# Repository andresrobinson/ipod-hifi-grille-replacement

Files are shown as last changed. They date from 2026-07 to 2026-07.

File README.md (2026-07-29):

# iPod Hi-Fi Grille Replacement

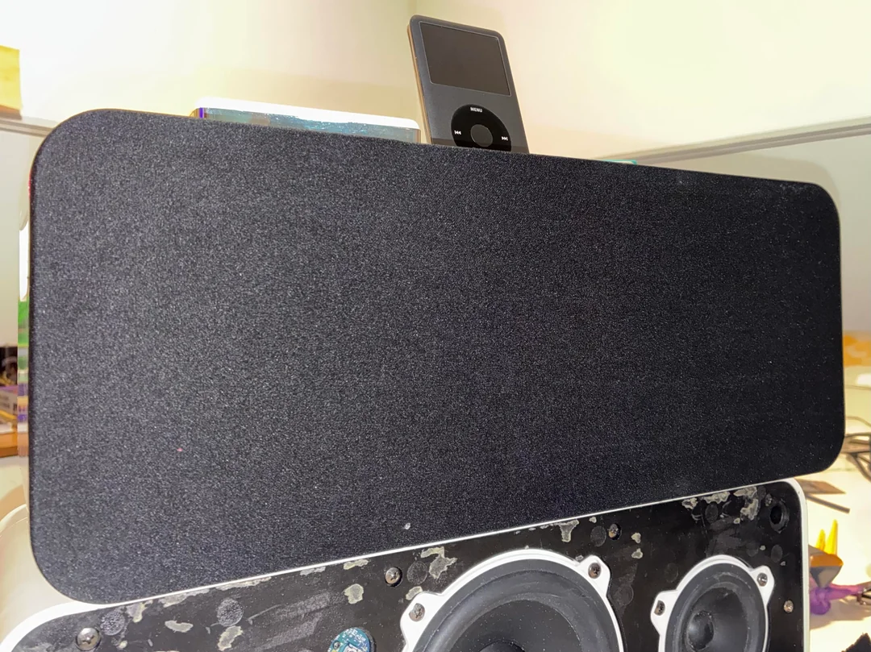
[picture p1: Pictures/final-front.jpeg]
Finished prototype


A 3D-printable replacement front grille frame for the **Apple iPod Hi-Fi A1121**, designed to be covered with fabric and mounted using replaceable screw-in pegs.

This project is meant for iPod Hi-Fi units with a missing or damaged original front grille. The replacement uses a printed support frame hidden behind fabric, so the visible front remains a clean fabric panel rather than a plastic printed mesh.

This is an independent repair/restoration project. It is not an original Apple part and is not affiliated with or endorsed by Apple.

---

## Quick Links

- [What this is](#what-this-is)
- [Files included](#files-included)
- [Parts overview](#parts-overview)
- [Materials](#materials)
- [Assembly](#assembly)
- [Fabric Installation (v1 - Glued)](#fabric-installation-v1)
- [Fabric Installation (v2 - Press Fit)](#fabric-installation-v2)
- [Mounting pegs](#mounting-pegs)
- [Known notes](#known-notes)
- [Development log](DEVELOPMENT.md)
- [Credits](#credits)
- [License](#license)

---

## What This Is {#what-this-is}

This is a replacement front grille assembly for the Apple iPod Hi-Fi.

The design is made from:

- three main printed frame sections;
- replaceable screw-in mounting pegs;
- glued fabric retaining strips;
- an optional assembly support to help align the frame sections during gluing;
- fabric stretched over the printed frame.

The printed frame is designed to sit behind the fabric. The fabric is the visible surface.

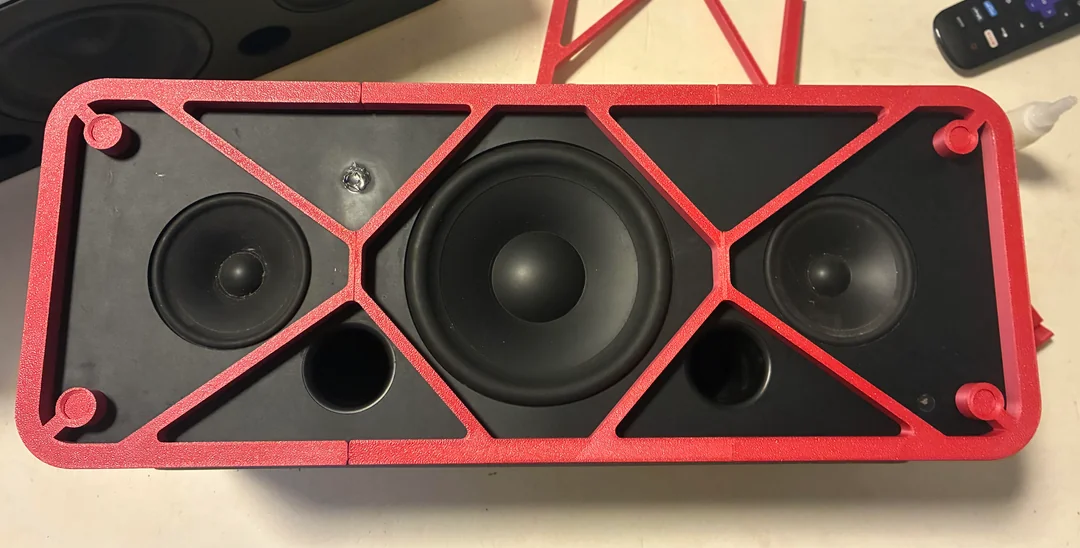
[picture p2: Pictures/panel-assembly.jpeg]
Panel assembly


---

## Files Included {#files-included}

The repository includes:

- a Fusion 360 source file;
- OBJ exports for the printable parts;
- documentation photos in the `Pictures/` folder;
- this README;
- a separate development log in [`DEVELOPMENT.md`](DEVELOPMENT.md).

The OBJ files are intended to include the main grille frame sections, replaceable pegs, retaining strips, and optional assembly support.

---

## Parts Overview {#parts-overview}

### Main Frame

The grille frame is split into three main parts so it can fit on a small 3D printer, including the Bambu Lab A1 Mini.

### Assembly Support

An optional assembly support is included to help align the frame sections during gluing. It is not part of the final visible grille.

Use of the assembly support is optional, but recommended.

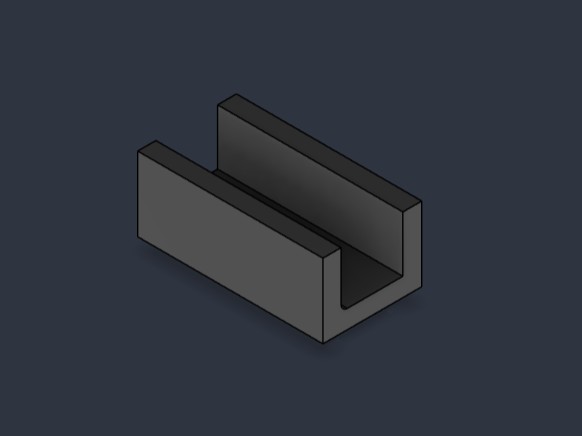
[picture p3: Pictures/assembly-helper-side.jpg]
Side assembly helper


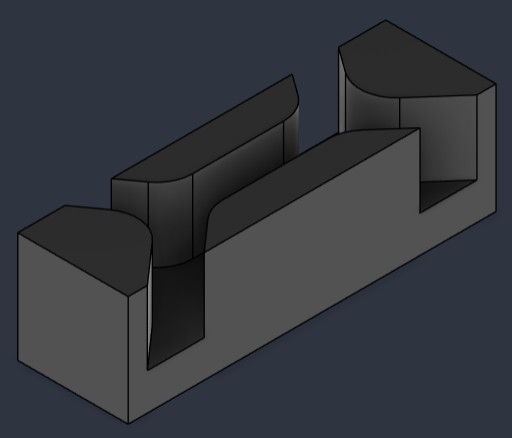
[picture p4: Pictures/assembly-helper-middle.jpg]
Middle assembly helper


### Retaining Strips

The retaining strips are used to hold the fabric in the fabric retention channel. There are two versions:
v1: Requires retainign strips to be glued in place after the fabric is stretched over the frame.

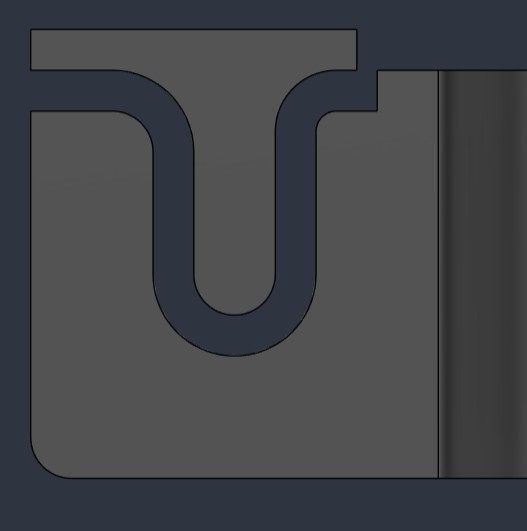
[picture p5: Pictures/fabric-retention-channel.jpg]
Fabric retention channel v1


v2: Allows retaining strip to be press fitted into the channel.

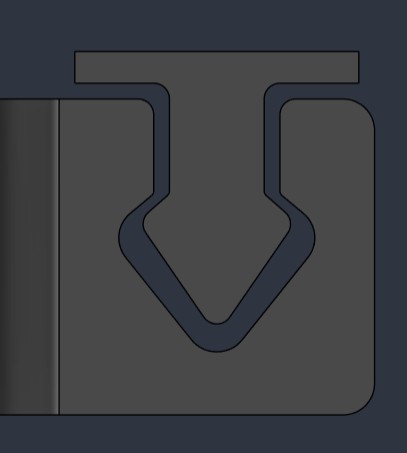
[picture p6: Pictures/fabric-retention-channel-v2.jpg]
Fabric retention channel v2


### Replaceable Pegs

The mounting pegs are separate screw-in parts. This allows the peg design to be changed later without reprinting the full frame.

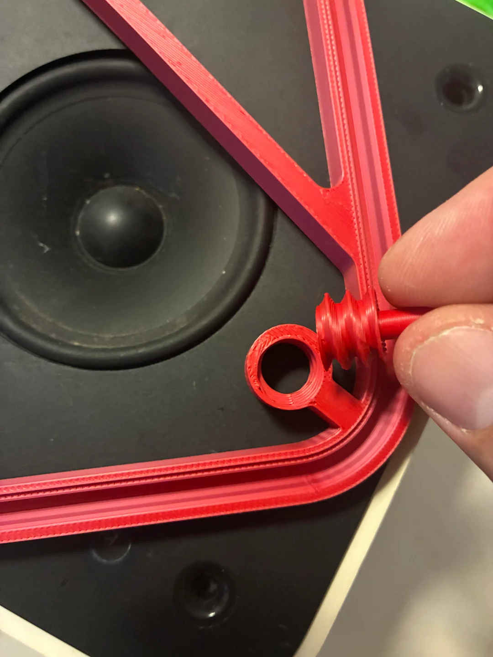
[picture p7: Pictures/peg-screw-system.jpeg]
Peg screw system


---

## Materials {#materials}

Recommended:

- printed frame parts;
- acoustically transparent speaker cloth, or thin fabric for testing;
- glue for joining the printed frame sections;
- glue for the fabric retaining strips;
- optional adhesive for locking the pegs after final test fitting.

For the first successful prototype, very thin neoprene was used as a proof-of-concept fabric. It gave good coverage and worked well mechanically, but it should still be treated as a test material rather than a confirmed acoustically transparent speaker cloth.

For a final audio-focused build, proper speaker grille cloth is recommended.

Avoid thick upholstery fabric, felt, dense neoprene, metal mesh, mosquito screen, or any fabric that noticeably muffles the speakers.

---

## Assembly {#assembly}

Suggested assembly order:

1. Print the three main frame sections.
2. Print the replaceable mounting pegs.
3. Print the fabric retaining strips.
4. Print the optional assembly support.
5. Test fit the main frame sections on the iPod Hi-Fi fascia.
6. Test fit the pegs in the mounting holes.
7. Adjust or swap peg type if needed.
8. Use the assembly support to align the main frame sections.
9. Glue the main frame sections together.
10. Let the frame glue fully cure.

---

## Fabric Installation (v1 - Glued) {#fabric-installation-v1}

The frame includes a fabric retention channel. The fabric is stretched over the frame, pressed into the channel, and held by glued retaining strips.

This is intended to make fabric installation cleaner than simply wrapping and gluing fabric around the back of the frame.

The retaining strips are not intended to be routinely removable. They are part of the final assembly.

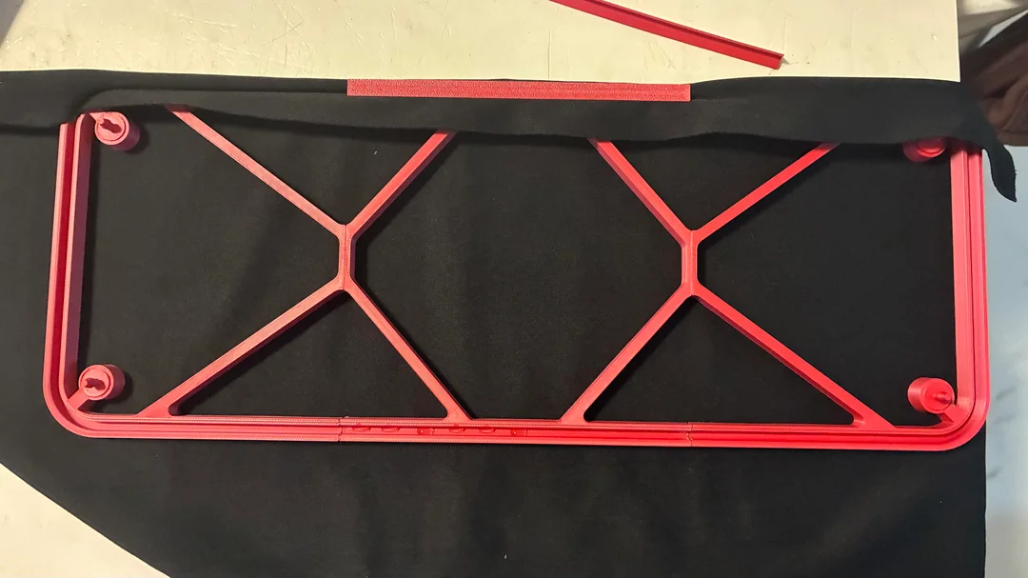
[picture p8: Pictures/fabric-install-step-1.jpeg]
Fabric installation step 1


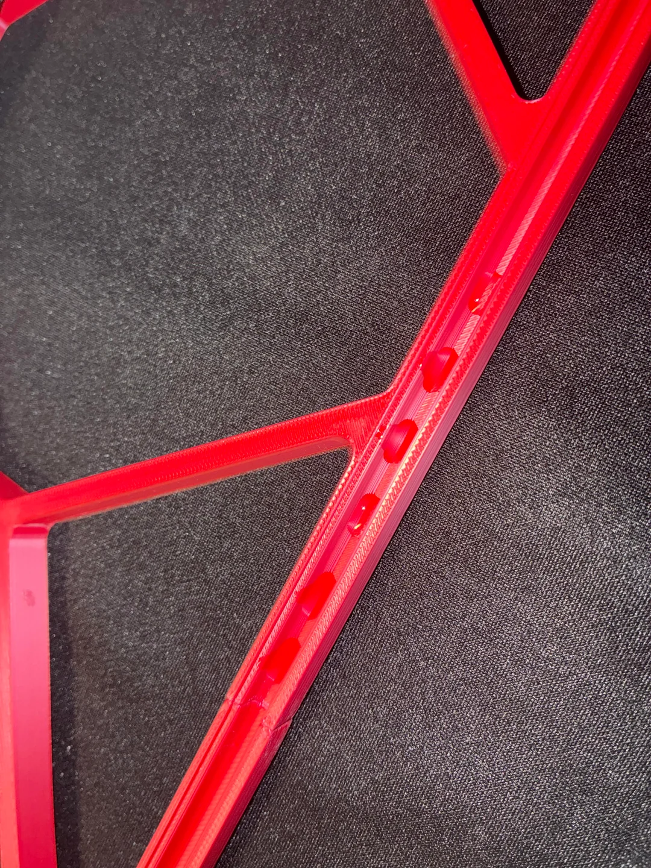
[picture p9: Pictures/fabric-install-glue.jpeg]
Fabric installation glue


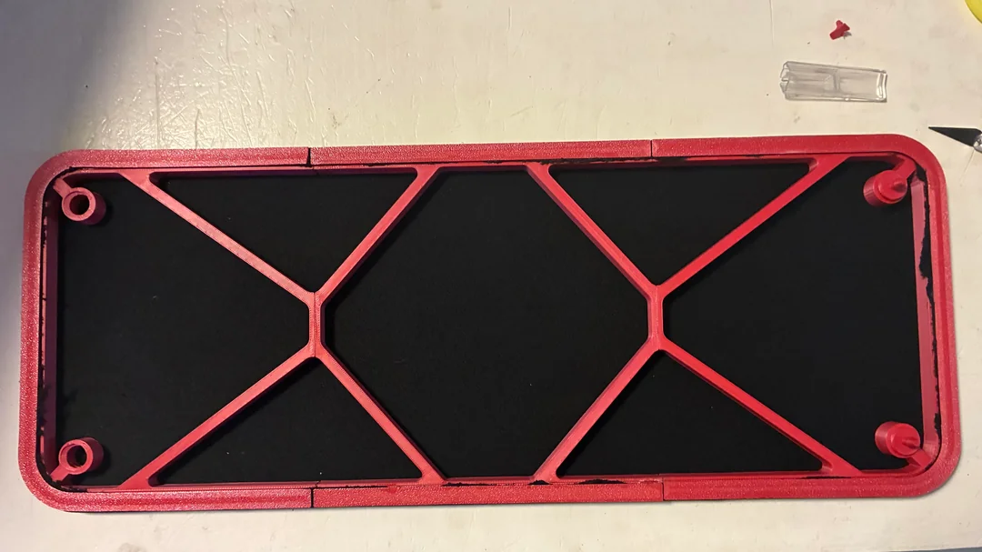
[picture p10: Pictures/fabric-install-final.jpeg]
Fabric installation final


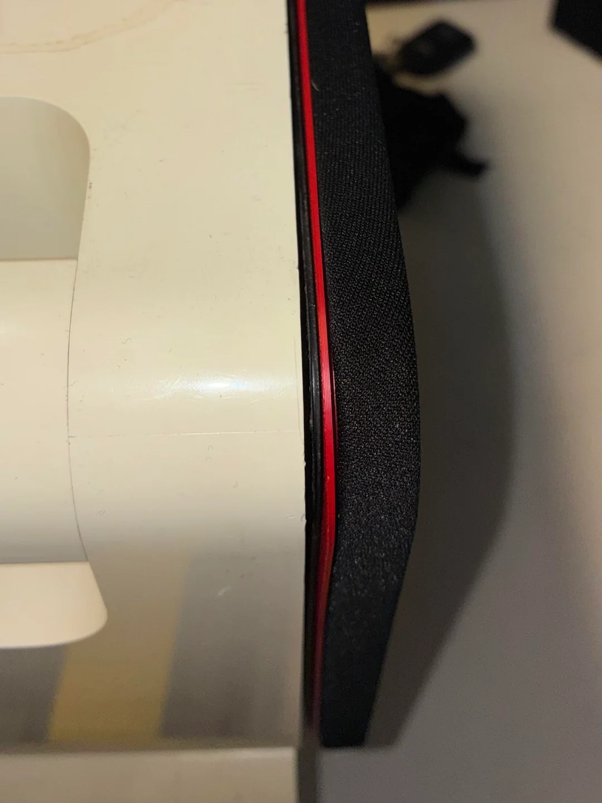
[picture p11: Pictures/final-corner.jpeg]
Final corner


## Fabric Installation (v2 - Press Fit) {#fabric-installation-v2}

The frame includes a fabric retention channel. The fabric is stretched over the frame, pressed into the channel, and held by press fit retaining strips.

This is intended to make fabric installation cleaner and more repeatable than simply wrapping and gluing fabric around the back of the frame or gluing into the channel.

The retaining strips are not intended to be routinely removable. They are part of the final assembly.

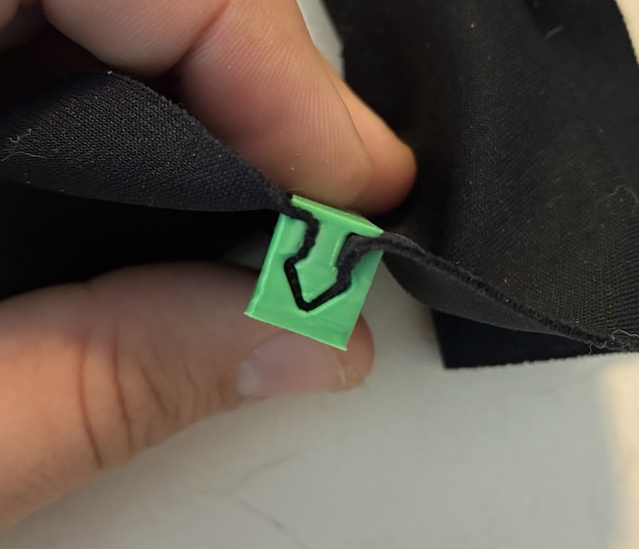
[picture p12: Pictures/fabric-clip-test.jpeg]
Fabric retention test


---

## Mounting Pegs {#mounting-pegs}

The mounting pegs are screw-in parts installed from the back of the grille frame.

Current thread specification:

```text
Thread diameter: 14 mm
Pitch: 3.5 mm
Profile: 60° trapezoidal
Tolerance class: 0.8 mm
```

The pegs can be installed before or after the fabric is mounted, since they do not interfere with the fabric or retaining strips.

If you do not plan to remove the pegs later, they can be glued in place after the final fit is confirmed.

### Mounting Hole Variation

A variation was found between two iPod Hi-Fi units.

On one unit, a 5 mm peg fit well. On another, the same peg would not go in. The fascia appears to have a small plastic retaining feature inside the mounting hole, probably intended to hold the original grille pegs in place.

Because of this, the design uses replaceable pegs.

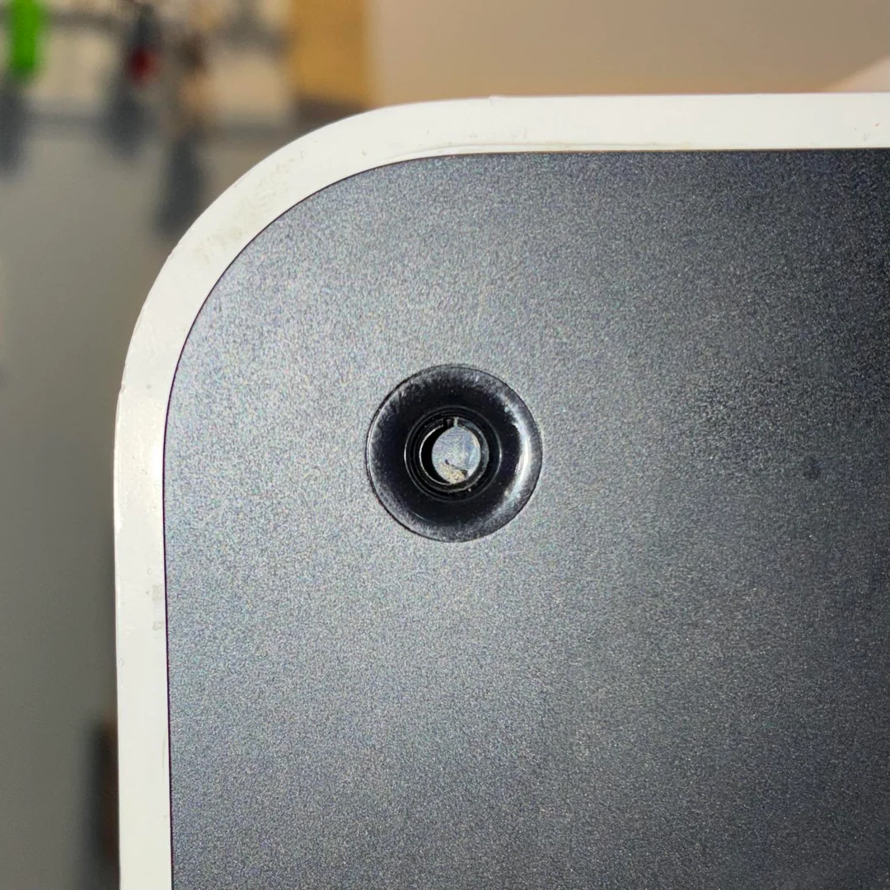
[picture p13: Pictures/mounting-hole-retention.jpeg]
Mounting hole with retention feature


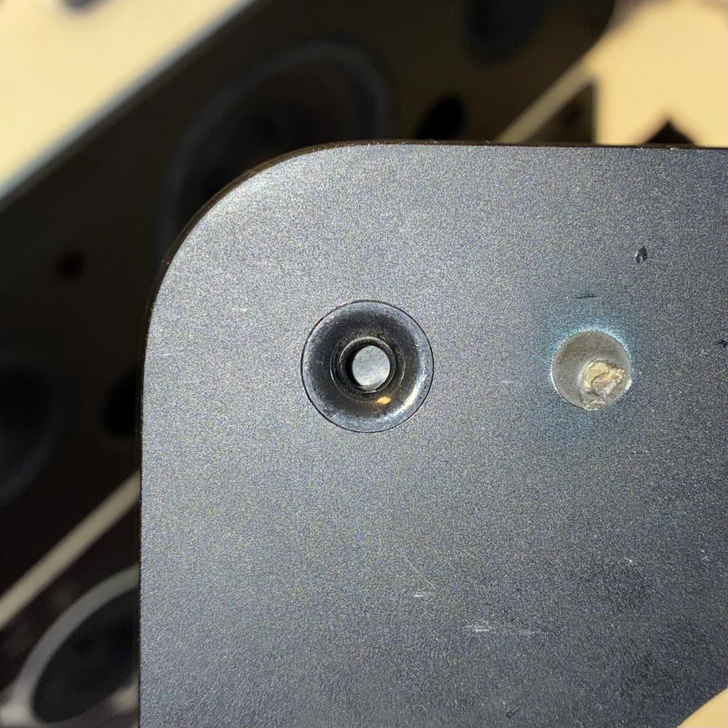
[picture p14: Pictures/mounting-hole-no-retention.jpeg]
Mounting hole without retention feature


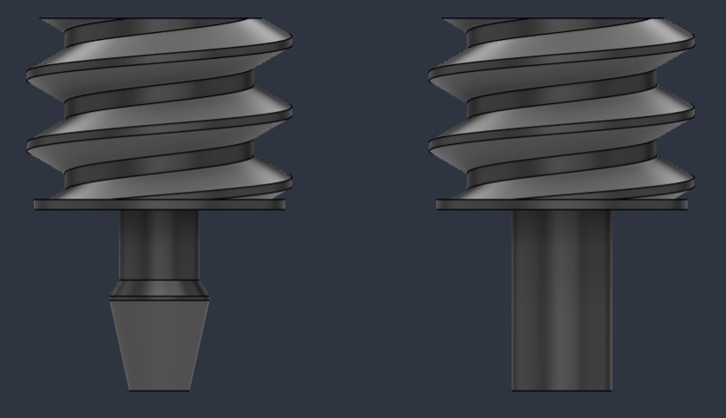
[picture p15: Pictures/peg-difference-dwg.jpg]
Peg type comparison


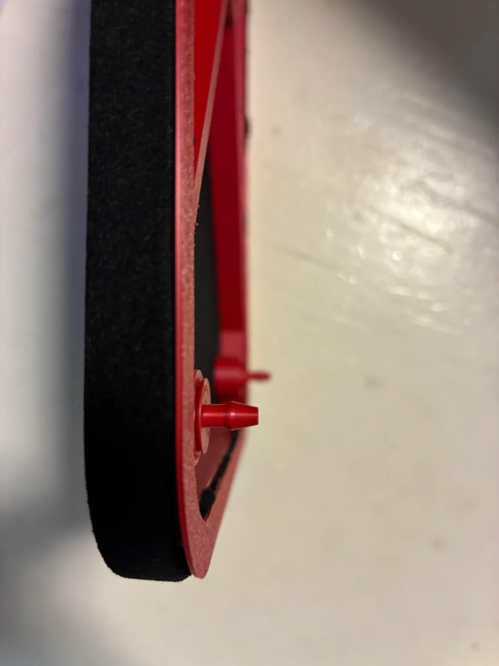
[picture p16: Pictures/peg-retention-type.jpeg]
Retention peg type


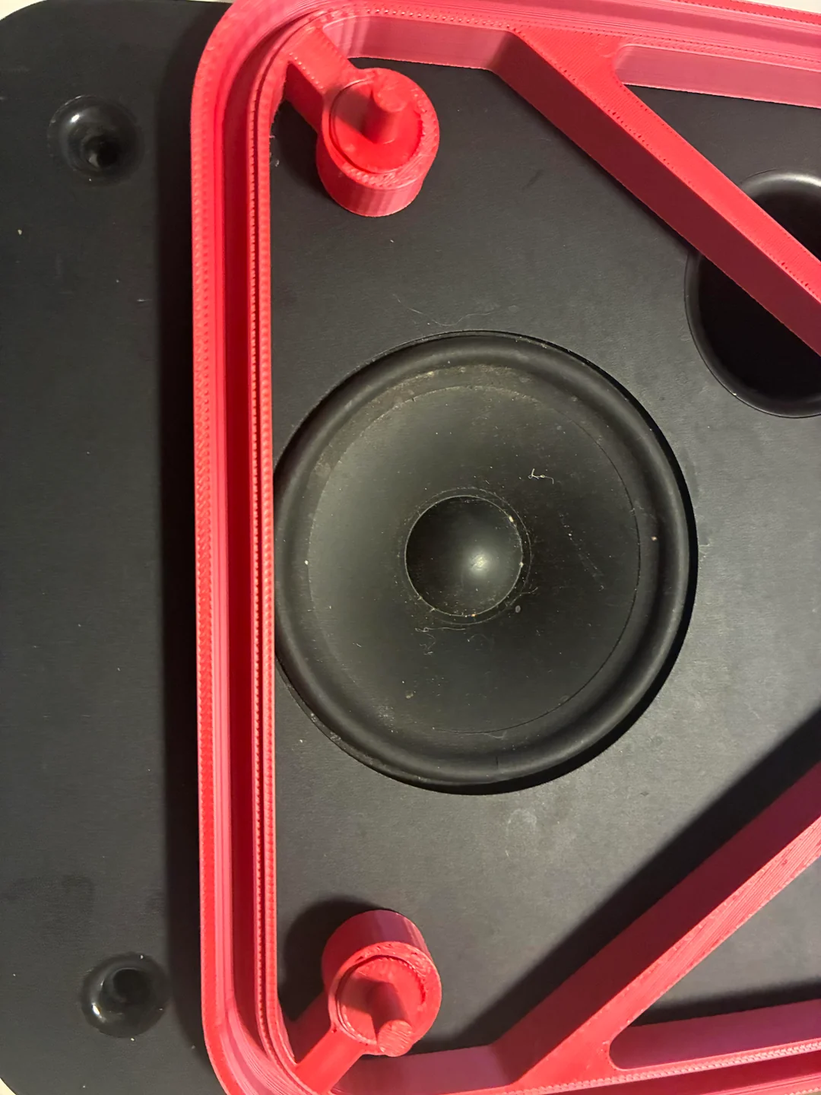
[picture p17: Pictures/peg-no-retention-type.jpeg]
No-retention peg type


---

## Known Notes {#known-notes}

- This is a replacement part, not an original Apple part.
- The fit was developed using real iPod Hi-Fi units, but small variation may exist between units.
- The mounting peg system is intentionally replaceable to make future improvements easier.
- The prototype fabric shown in some photos is very thin neoprene. It is useful for proving the assembly, but proper speaker grille cloth is still recommended for best acoustic transparency.
- Test fit everything before gluing.
- Do not force the pegs into the fascia. If the fit is too tight, change the peg design or adjust the print.

---

## Development Log {#development-log}

The design process, measurement approach, corner-radius tests, peg-spacing work, and thread decisions are documented separately in [`DEVELOPMENT.md`](DEVELOPMENT.md).

The README is kept focused on printing and assembly so people who only want to replicate the part do not need to read the full development history.

---

## Credits {#credits}

This project was helped by the following public resources:

- [`jake-b/iPod-HiFi-Tweeters`](https://github.com/jake-b/iPod-HiFi-Tweeters), which documents iPod Hi-Fi disassembly, fascia work, and speaker mesh frame construction.
- [`BalzGuenat/CustomThreads`](https://github.com/BalzGuenat/CustomThreads), which provides Fusion 360 thread profiles designed for 3D-printed threads.
-  Reddit user `u/sparkyblaster`, for the helpful comment about the original rounded peg shape in the [Day 2 Reddit thread](https://www.reddit.com/r/ipod/comments/1v1avmh/day_2_of_trying_to_make_a_mesh_panel_for_my_ipod/).

---

## Disclaimer {#disclaimer}

Apple, iPod, and iPod Hi-Fi are trademarks of Apple Inc.

This project is independent and unofficial. It is not affiliated with, sponsored by, or endorsed by Apple.

The files and instructions are provided for repair, restoration, and educational purposes. Use them at your own risk.

Avoid adhesives or mounting methods that could permanently damage the speaker enclosure.

---

## License {#license}

Unless otherwise stated, documentation, images, and design files in this repository are shared under the Creative Commons Attribution-NonCommercial-ShareAlike 4.0 International License.

This means you may copy, modify, and share the work for non-commercial purposes, as long as you give credit and share adaptations under the same license.

If any third-party resources are included or adapted, their original licenses and attribution requirements must also be respected.

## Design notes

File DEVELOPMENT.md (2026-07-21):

# Development Log

This file documents the design process for the iPod Hi-Fi grille replacement.

The main [`README.md`](README.md) is kept focused on printing and assembly. This file is for the measurement process, prototypes, design reasoning, and lessons learned.

---

## Starting Point

The project started with two Apple iPod Hi-Fi units.

Both were missing the original front grille. One unit also had a faulty 30-pin dock connector, which was later replaced using the dock assembly from the second unit. After the dock swap, the repaired unit worked properly and could be used as the main reference unit for the grille replacement.

The goal was to recreate the missing grille as a practical repair part using 3D printing and fabric.

The design target was not a printed visible mesh. The intended replacement is a hidden support frame covered with fabric, similar in appearance to the original fabric front panel.

---

## Design Constraints

The replacement needed to:

- fit the original front grille opening;
- use the original mounting-hole locations;
- avoid blocking the speaker drivers;
- fit on a small printer, specifically a Bambu Lab A1 Mini;
- be split into multiple printable pieces;
- support fabric installation cleanly;
- allow the mounting pegs to be changed if needed.

---

## Corner Radius

The first challenge was the corner radius.

The overall grille shape looks simple, but the corners are important. If the radius is wrong, the part will immediately look and fit wrong.

Because the iPod Hi-Fi was designed in the United States, the initial assumption was that some dimensions might be based on imperial measurements. A rough measurement suggested that the corner radius was close to 1 inch.

A radius gauge was printed and test-fitted against the speaker opening. This confirmed the corner radius as:

```text
Corner radius: 25.4 mm / 1 inch
```

This became the first fixed reference for the CAD model.

---

## Mounting Peg Offset

After the corner radius was confirmed, the next problem was locating the original mounting holes.

The holes are not located at the center of the corner radius. Because of that, a simple rounded rectangle was not enough. The design had to match the corner curve and the peg location independently.

The mounting hole offsets were measured from each side edge of the grille opening.

Several small corner test pieces were printed to test the relationship between:

- the 25.4 mm corner radius;
- the side edges;
- the original mounting holes;
- the peg position relative to the corner.

These early test pieces were only used during development and are not included in the repository.

---

## Side Assembly Prototype

Once the corner radius and local peg offsets were good, the next step was finding the distance between the mounting pegs along one side.

A side assembly prototype was designed. This part combined two side corners into one printed piece, so both corner peg positions could be tested at the same time.

This verified:

- the distance between the upper and lower side pegs;
- the alignment of both corners with the fascia;
- whether the 25.4 mm radius still fit correctly as part of a longer piece;
- whether the peg locations matched the original holes without forcing the print.

After that side assembly fit correctly, a second copy was printed.

With two side assemblies available, the horizontal distance between the left and right mounting peg locations could be measured and confirmed.

This staged process built the design from known-good references:

1. corner radius;
2. corner-to-peg offset;
3. vertical peg spacing;
4. horizontal peg spacing;
5. full grille frame layout.

---

## Internal Reinforcements

After the outer geometry and mounting peg positions were established, the internal reinforcement layout was sketched by hand.

The goal was to keep the frame flat and stable while avoiding unnecessary obstruction in front of the speakers.

The internal reinforcement layout was drawn around the speaker areas using a pencil, then translated into Fusion 360 for the first full CAD draft.

---

## First Full CAD Draft

The first full design was created in Fusion 360.

The design was split into three main frame parts so it could fit on a small printer such as the Bambu Lab A1 Mini.

The first full concept included:

- three main frame sections;
- screw-in replaceable pegs;
- a fabric retention channel;
- separate retaining strips for the fabric;
- an optional assembly support to help align the frame during gluing.

---

## Fabric Retention

The fabric mounting system was inspired by the documented speaker mesh frame construction in the [`jake-b/iPod-HiFi-Tweeters`](https://github.com/jake-b/iPod-HiFi-Tweeters) project.

The replacement grille uses a fabric retention channel and separate retaining strips.

The idea is:

1. stretch fabric over the printed frame;
2. press the fabric into the channel;
3. glue retaining strips over the fabric;
4. trim the excess fabric after the glue cures.

The retaining strips are glued in place, similar in spirit to the original bonded construction.

---

## Mounting Hole Variation

During testing, a variation was found between two iPod Hi-Fi units.

A 5 mm peg fit well in one unit, but would not fit correctly in the other. On closer inspection, the fascia appears to include a small plastic opening or retaining feature inside the mounting hole.

This feature was probably intended to hold the original grille pegs in place. It may have originally used a rounded or deformable shape.

Because of this, the mounting pegs were changed from fixed printed features to replaceable screw-in parts.

This makes it possible to improve or change the peg design later without reprinting the full grille frame.

---

## Replaceable Peg Threads

The peg system uses printed threads.

Standard Fusion 360 thread profiles are not always ideal for 3D printing, so the project used the [`BalzGuenat/CustomThreads`](https://github.com/BalzGuenat/CustomThreads) Fusion 360 thread profiles.

The selected thread specification is:

```text
Thread diameter: 14 mm
Pitch: 3.5 mm
Profile: 60° trapezoidal
Tolerance class: 0.8 mm
```

The tolerance was selected through test prints. The goal was to find a thread that could be screwed together securely without being too tight.

The pegs screw in from the back of the frame. They can be installed before or after fabric installation because they do not interfere with the fabric or retaining strips.

If the pegs do not need to remain removable, they can be glued in place after final test fitting.

The rounded-peg possibility was also pointed out by Reddit user `u/sparkyblaster` in the Day 2 Reddit thread, and credit is due for that observation.

---

## Assembly Support

An optional assembly support was added to help align the three main frame sections during gluing.

This support is not part of the final visible grille. It is a temporary aid to keep the frame sections positioned correctly while the adhesive cures.

It is optional, but recommended.

---

## Prototype Fabric

For the first successful assembly, very thin neoprene was used.

The neoprene was less than approximately 1 mm thick and gave good visual coverage. It was useful for validating:

- fabric handling;
- the retention channel;
- the glued retaining strips;
- the overall assembled appearance.

However, neoprene should be treated as a prototype fabric. Even when thin, it may not be as acoustically transparent as real speaker grille cloth.

For a final audio-focused version, proper acoustically transparent speaker cloth is still recommended.

---

## Current Result

The assembled prototype fit well and produced a result good enough to publish.

The current public release is intended as a practical first version. Future improvements may include:

- alternate peg designs;
- more fabric testing;
- refinements to the retention strips;
- small fit improvements based on other iPod Hi-Fi units.

---

## Notes for Future Work

Possible future improvements:

- Add more peg variants for units with different mounting-hole behavior.
- Test real speaker grille cloth against the neoprene prototype.
- Add photos of each OBJ part separately.
- Add print orientation screenshots.
- Add a simplified assembly diagram.
- Add measured dimensions if useful for contributors.

---

## References

- [`jake-b/iPod-HiFi-Tweeters`](https://github.com/jake-b/iPod-HiFi-Tweeters)
- [`BalzGuenat/CustomThreads`](https://github.com/BalzGuenat/CustomThreads)

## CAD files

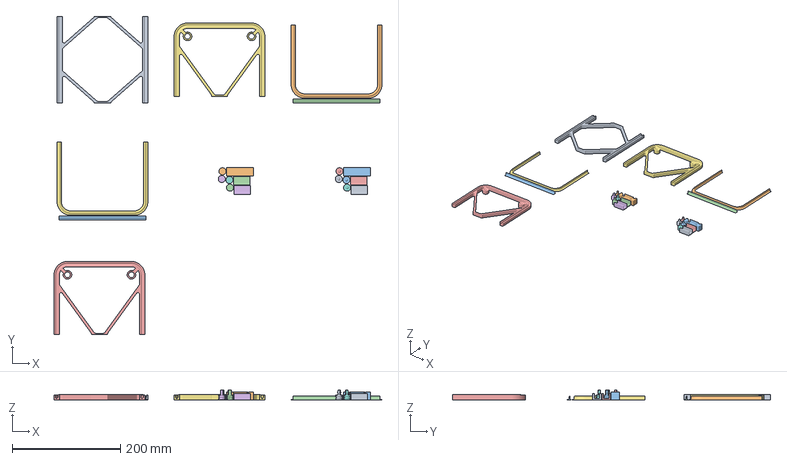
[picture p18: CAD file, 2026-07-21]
Mesh Panel.3mf
605.4 x 587.7 x 18.5 mm
Mid-Body.obj
Assembl Support.obj x 2
Assembly Support - Side.obj x 4
Side-Body.obj x 2
Pin-Complete.obj x 4
Pin-Complete-Retainer.obj x 4
Side-Bracket.obj x 2
Mid-Bracket.obj x 2

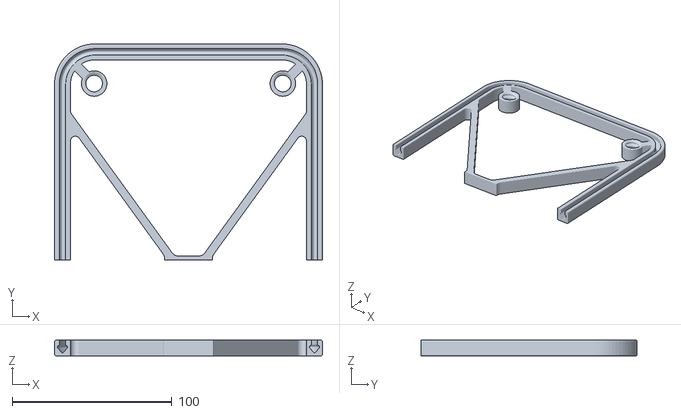
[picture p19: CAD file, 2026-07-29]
OBJ/v2/Frame - Side v2.obj
167.8 x 135.4 x 10.0

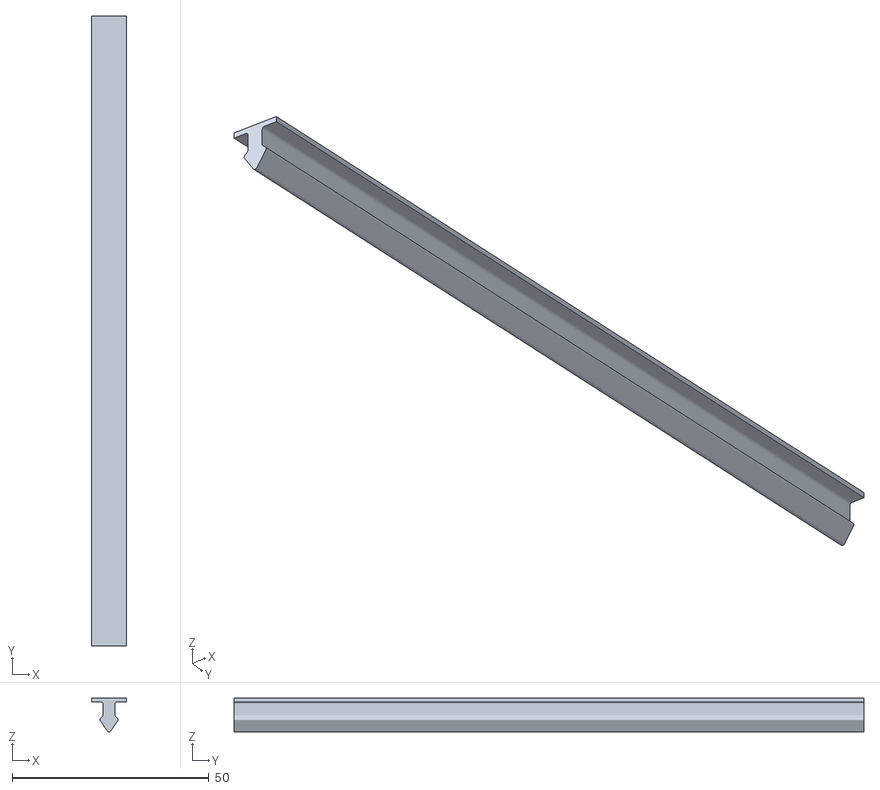
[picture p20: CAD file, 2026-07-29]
OBJ/v2/Retaining Strip - Middle v2.obj
9.00 x 160.0 x 8.62

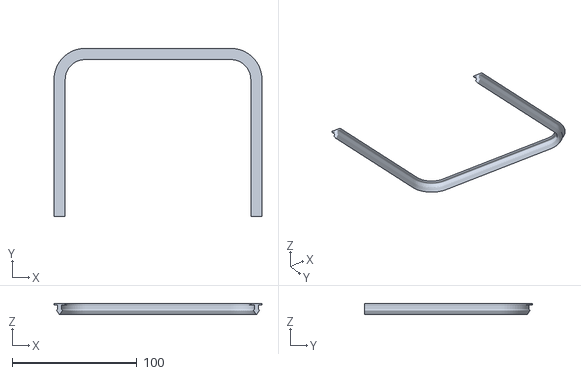
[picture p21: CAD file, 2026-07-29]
OBJ/v2/Retaining Strip - Side v2.obj
166.8 x 134.9 x 8.62

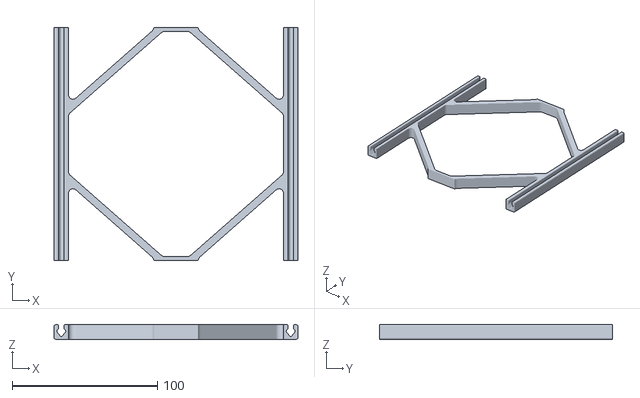
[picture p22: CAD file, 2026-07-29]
OBJ/v2/Frame - Middle v2.obj
167.8 x 160.0 x 10.0

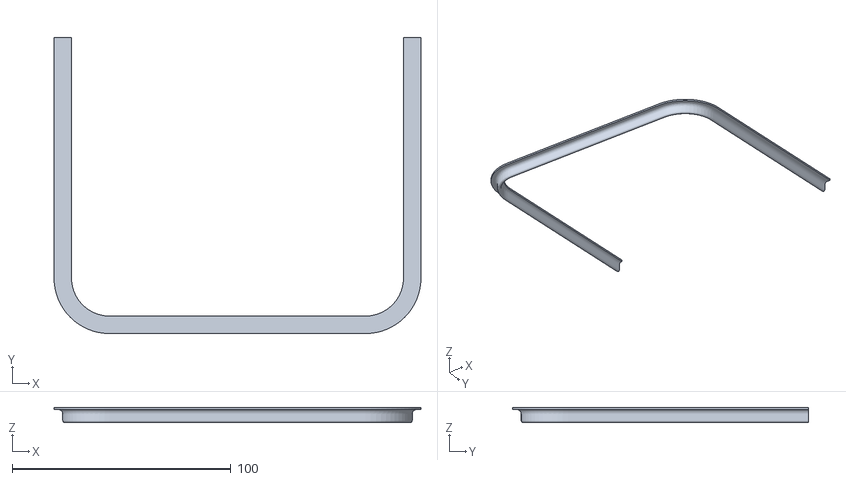
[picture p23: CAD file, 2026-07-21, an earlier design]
OBJ/v1/Retaining Strip - Side.obj
167.8 x 135.4 x 7.00

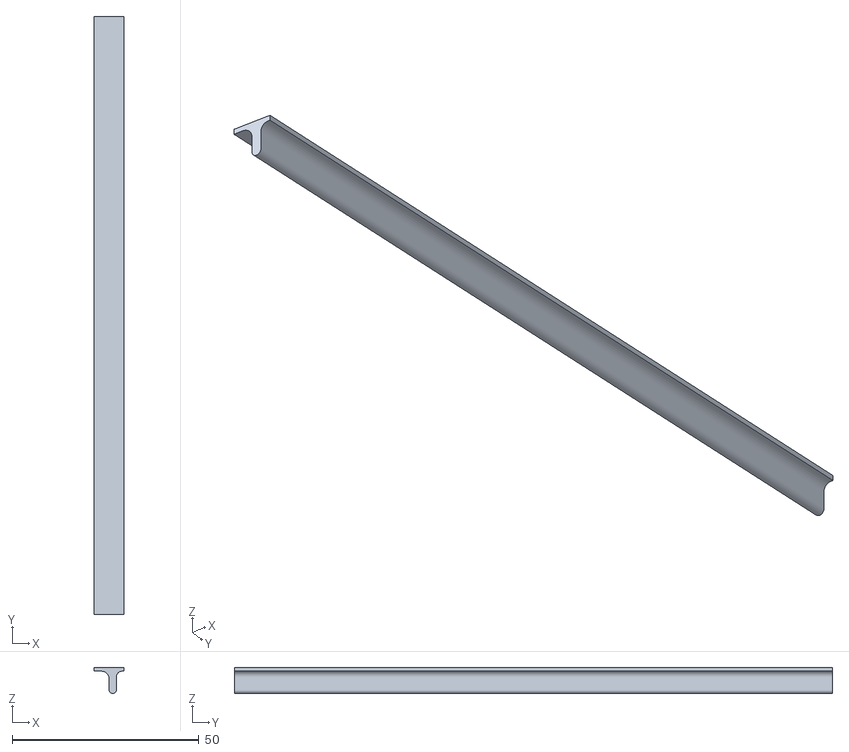
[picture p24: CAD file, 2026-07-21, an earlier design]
OBJ/v1/Retaining Strip - Middle.obj
8.00 x 160.0 x 7.00

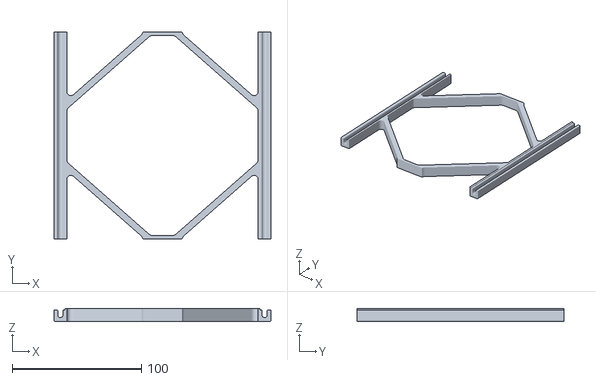
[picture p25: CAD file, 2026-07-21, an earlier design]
OBJ/v1/Frame - Middle.obj
167.8 x 160.0 x 10.0

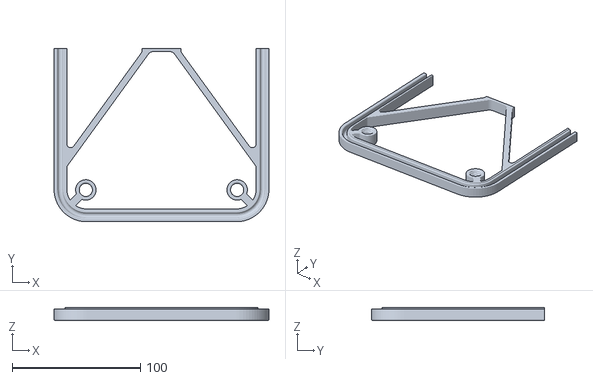
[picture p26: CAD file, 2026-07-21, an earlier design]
OBJ/v1/Frame - Side.obj
167.8 x 135.4 x 10.0

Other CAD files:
Mesh Panel.f3d

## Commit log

2026-07-20 Revise README with comprehensive project details
    Updated README to provide detailed project information, including goals, status, design approach, prototype development, and assembly instructions for the iPod Hi-Fi grille replacement project.
2026-07-20 Add assembly and installation documentation images
    Add 15 documentation images showing assembly helpers, fabric installation steps, mounting hole variations, peg system details, and final assembly results.
2026-07-21 Adding OBJ, F3D and 3MF files
    [Mesh Panel.3mf, Mesh Panel.f3d]
2026-07-29 Release of v2
    - Added support for press fit retaining strip.
    [Frame - Middle v2.obj, Frame - Middle.obj, Frame - Side v2.obj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]
2026-07-29 README: add anchors and remove print settings
    Add explicit HTML anchors to major README headings to improve in-document linking and navigation. Remove the 'Print Settings' section to declutter the guide. Normalize an image filename extension (fa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
